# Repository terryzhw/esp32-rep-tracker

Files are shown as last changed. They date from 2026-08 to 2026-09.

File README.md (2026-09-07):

# Curl Tracker: Wearable Bicep Curl Coach (Work In Progress)

## What is Curl Tracker?

Curl Tracker is a wearable bicep curl tracker that uses an ESP32-C3 Super Mini alongside a MPU-6500 IMU to count reps, measure curl speed, and evaluate form in real-time. It uses a on-device classifier to distinguish good reps from common curl form faults. Curl Tracker displays live rep metrics to a SSD1306 OLED and streams data over MQTT to be plotted on a Python/matplotlib client. It also provides haptic feedback and monitoring of device state.

## Bicep-Curl Classifier
### Training:



### Collecting:


### Working Video:

## Breadboard Prototype

### Design Choices:

- Power: 3.7V LiPo (range: 3.0V - 4.2V) with a TP4056 module for charging managment. MT3608 module converts the varying 3.7V Lipo to a stable 5V source. A mechanical switch is used as a on/off switch. 

- MCU & Peripherals: ESP32-C3 Super Mini is the MCU that serves as the brain for the project. MPU-6500 IMU and SSD1306 share a I2C bus which the ESP32 uses to communicate. A push button is used to provide data collection input to label reps while gathering training data for the classifier.

- Feedback: A status LED exists which turns on if any of the electronic malfunction. The OLED displays rep count, sets, and status of MQTT. The vibration motor, paired with a flyback diode circuit for back-EMF protection, is used for haptic feedback.
  
Curl Tracker breadboard prototype

## KiCad Schematic & PCB layout 

### Design Choices: 

- ESP32-C3-MINI-1 module: Using a pre-certified module means the RF design is already done and the FCC/CE certification carries over, so I avoid the antenna layout, matching network, and re-testing that a bare C3 would require.
  
- MPU6500 → BMI270: The MPU6500 is end-of-life and no longer recommended for new designs. The BMI270 is Bosch's current-generation IMU with active vendor support and drivers in most major frameworks.
  
- TP4056 → MCP73831: Swapped the TP4056 for Microchip's MCP73831. Better documented, properly sourced through mainstream distributors, and easier to justify in a design review.
  
- MT3608 → TPS63001: A LiPo swings from 4.2 V down to 3.0 V, which straddles the 3.3 V rail from both directions. A boost-only converter or an LDO can't hold regulation across that whole range, so the TPS63001 buck-boost keeps 3.3 V stable through the full discharge curve, including the current spikes when the ESP32's radio transmits.
  
- USB-C: The current connector standard: reversible, mechanically more durable than micro-B, and what any user will already have a cable for.
  
- JST-PH for battery and motor: Keyed housings so the connectors can't be seated backwards, and they're cheap, common, and rated well past the current this board draws.

schematic
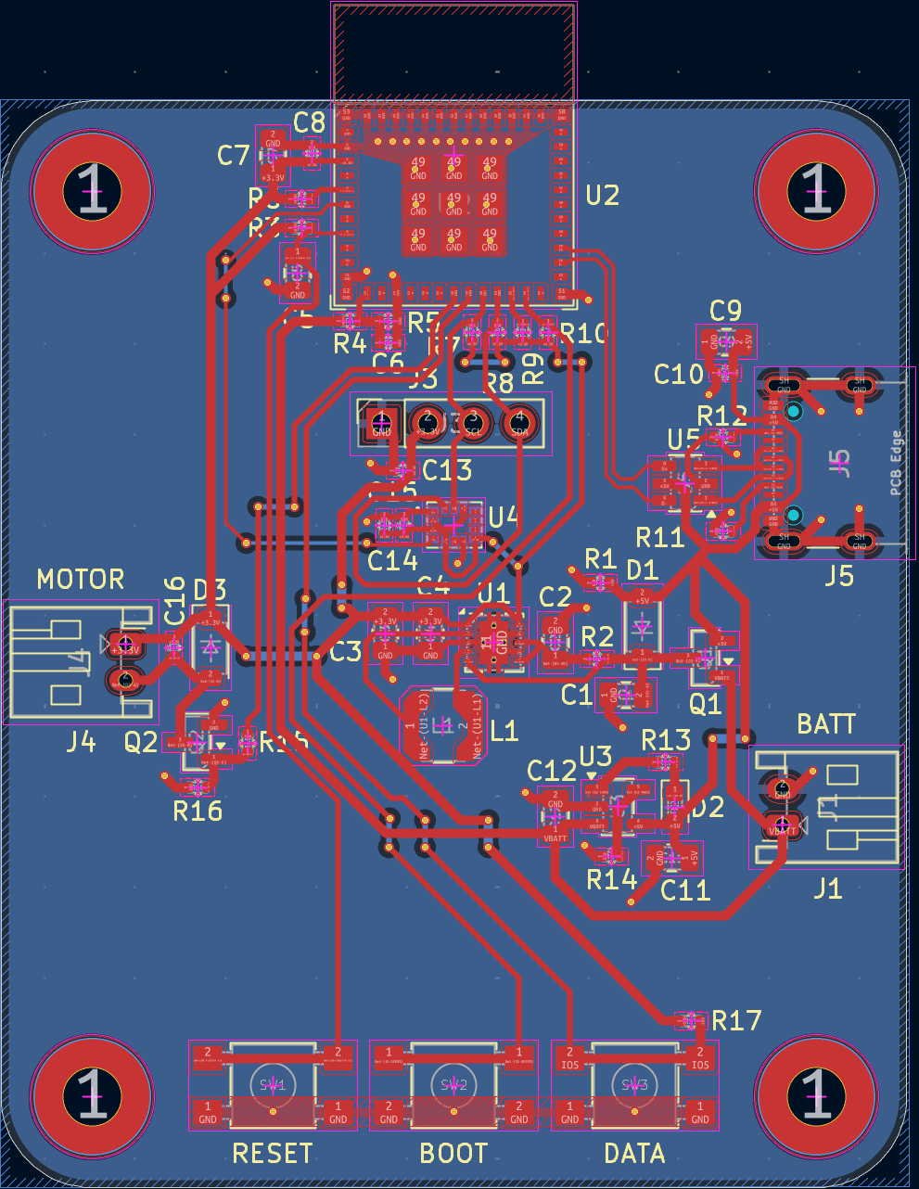
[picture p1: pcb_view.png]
pcb_view

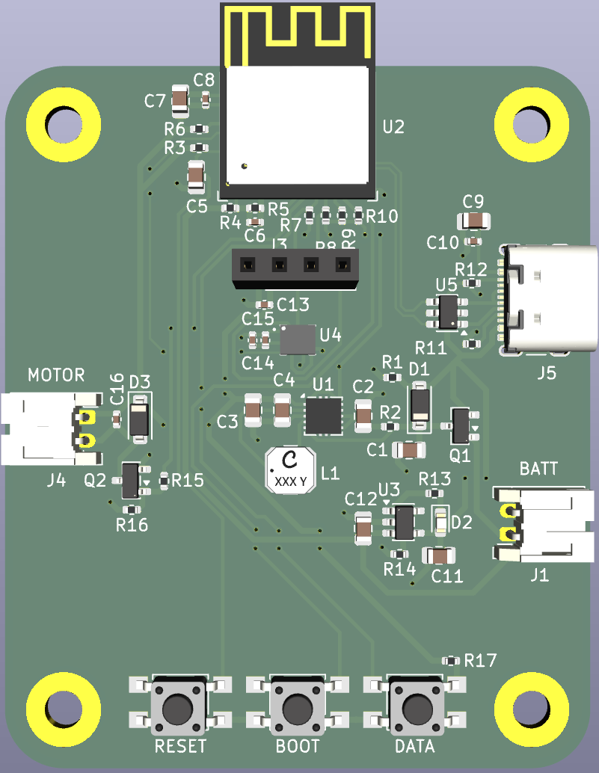
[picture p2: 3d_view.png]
3d_view

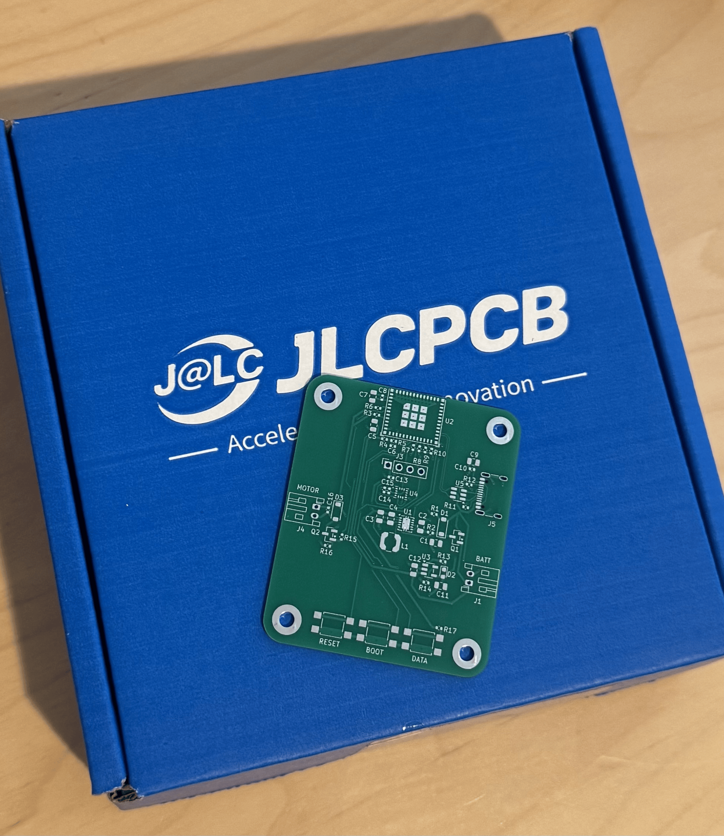
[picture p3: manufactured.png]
manufactured


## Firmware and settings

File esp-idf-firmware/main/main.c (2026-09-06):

// Bicep curl counter. IMU on the forearm -> complementary filter -> tiny NN
// that says "curling / not curling" -> count the rising edges.
//
// Split into tasks mainly because the OLED redraw is slow and blocking on it
// would wreck the 100 Hz sample timing.

#include <stdio.h>
#include <string.h>
#include <math.h>
#include <stdbool.h>

#include "freertos/FreeRTOS.h"
#include "freertos/task.h"
#include "driver/i2c.h"
#include "driver/gpio.h"
#include "driver/ledc.h"
#include "esp_timer.h"
#include "esp_log.h"

#include "hal/gpio_types.h"
#include "u8g2.h"
#include "mpu6500.h"
#include "model.h"

static const char *TAG = "curl_tracker";

#define I2C_SDA_PIN         8
#define I2C_SCL_PIN         9
#define LED_PIN             10
#define BUTTON_PIN          4
#define MOTOR_PIN           3

#define I2C_PORT            I2C_NUM_0
#define I2C_FREQ_HZ         400000

// Button pulls to ground, so pressed reads low. Naming these stops me from
// getting the polarity backwards every time I touch this code.
#define BUTTON_RELEASED     1
#define BUTTON_PRESSED      0

// Gyro is smooth but drifts, accelerometer is drift-free but jumps around
// whenever the arm accelerates. 0.9 leans on the gyro for responsiveness and
// lets gravity slowly pull the estimate back straight. Worth re-tuning if the
// angle either wanders over a long set or looks too noisy to classify.
#define ALPHA               0.90f

// Sensor runs at 1 kHz internally and divides by (1 + SRD), so this is 100 Hz.
#define SAMPLE_RATE_DIV     9
#define DT                  ((1.0f + SAMPLE_RATE_DIV) / 1000.0f)

#define RAD_TO_DEG          (180.0f / (float)M_PI)

#define IMU_PERIOD_MS       10
#define DISPLAY_PERIOD_MS   50   // shares the bus with the IMU, so don't push it
#define BUTTON_PERIOD_MS    20
#define SERIAL_PERIOD_MS    50
#define INFERENCE_PERIOD_MS 10

#define MOTOR_BUZZ_MS       200  // short enough not to overlap the next rep

#define NUM_FEATURES        2
#define INPUT_SIZE          (MODEL_WINDOW_SIZE * NUM_FEATURES)
#define HIDDEN0_SIZE        16
#define HIDDEN1_SIZE        8

#define CURL_THRESHOLD      0.5f
#define INFERENCE_STRIDE    5

static mpu6500_t imu;
static u8g2_t u8g2;

// Shared between tasks. Everything here is word sized, so a torn read isn't
// possible and I skipped the mutex.
static float roll_deg  = 0.0f;
static float pitch_deg = 0.0f;
static volatile bool filter_ready = false;
static volatile bool collecting = false;
static volatile int button_level = BUTTON_RELEASED;
static volatile int rep_count = 0;
static volatile int set_count = 0;

static TaskHandle_t motor_task_handle = NULL;

static uint32_t millis(void)
{
    return (uint32_t)(esp_timer_get_time() / 1000ULL);
}

// u8g2 is platform agnostic, so it calls back into these two for delays and
// for anything that touches the bus.
static uint8_t u8x8_gpio_and_delay_esp32(u8x8_t *u8x8, uint8_t msg,
                                         uint8_t arg_int, void *arg_ptr)
{
    switch (msg) {
        case U8X8_MSG_DELAY_MILLI:
            vTaskDelay(pdMS_TO_TICKS(arg_int));
            break;
        case U8X8_MSG_GPIO_AND_DELAY_INIT:
            break;
        default:
            break;
    }
    return 1;
}

// Collect the whole frame first and send it as one transaction. A separate
// I2C transfer per byte would spend most of the time on start/stop overhead.
static uint8_t u8x8_byte_esp32_i2c(u8x8_t *u8x8, uint8_t msg,
                                   uint8_t arg_int, void *arg_ptr)
{
    static uint8_t buf[128];
    static size_t buf_idx;
    uint8_t *data;

    switch (msg) {
        case U8X8_MSG_BYTE_START_TRANSFER:
            buf_idx = 0;
            break;

        case U8X8_MSG_BYTE_SEND:
            data = (uint8_t *)arg_ptr;
            while (arg_int > 0) {
                buf[buf_idx++] = *data++;
                arg_int--;
            }
            break;

        case U8X8_MSG_BYTE_END_TRANSFER: {
            // u8g2 keeps the address pre-shifted, ESP-IDF wants the raw 7 bits
            uint8_t addr = u8x8_GetI2CAddress(u8x8) >> 1;
            i2c_master_write_to_device(I2C_PORT, addr, buf, buf_idx,
                                       pdMS_TO_TICKS(100));
            break;
        }

        case U8X8_MSG_BYTE_INIT:
        case U8X8_MSG_BYTE_SET_DC:
            // bus is already up, and I2C has no DC line
            break;
    }
    return 1;
}

static void i2c_bus_init(void)
{
    i2c_config_t conf = {
        .mode = I2C_MODE_MASTER,
        .sda_io_num = I2C_SDA_PIN,
        .scl_io_num = I2C_SCL_PIN,
        .sda_pullup_en = GPIO_PULLUP_ENABLE,
        .scl_pullup_en = GPIO_PULLUP_ENABLE,
        .master.clk_speed = I2C_FREQ_HZ,
    };
    i2c_param_config(I2C_PORT, &conf);
    i2c_driver_install(I2C_PORT, I2C_MODE_MASTER, 0, 0, 0);
}

static bool imu_init(void)
{
    if (!mpu6500_init(&imu, I2C_PORT)) {
        return false;
    }

    // 4 g leaves headroom over the 1 g resting reading for the fast part of
    // the curl. A curl is around 1 Hz, so the 20 Hz low pass drops tremor and
    // strap slap without touching the motion I care about.
    mpu6500_set_accel_range(&imu, MPU6500_ACCEL_RANGE_4G);
    mpu6500_set_gyro_range(&imu, MPU6500_GYRO_RANGE_500DPS);
    mpu6500_set_dlpf(&imu, MPU6500_DLPF_20HZ);
    mpu6500_set_srd(&imu, SAMPLE_RATE_DIV);
    return true;
}

static void task_sample_imu(void *pv)
{
    ESP_LOGI(TAG, "IMU task started");

    if (!imu_init()) {
        ESP_LOGE(TAG, "Error starting IMU");
        vTaskDelete(NULL);
        return;
    }
    ESP_LOGI(TAG, "IMU initialized OK");

    // Header for the logging mode below, so the capture can be piped straight
    // into a csv and loaded by the training script.
    printf("timestamp_ms,roll,pitch,label\n");

    for (;;) {
        if (mpu6500_read(&imu)) {
            float ax = imu.accel[0];
            float ay = imu.accel[1];
            float az = imu.accel[2];
            float gx = imu.gyro[0];
            float gy = imu.gyro[1];

            // Gravity is the only absolute reference we have for tilt.
            float accel_roll  = atan2f(ay, -az) * RAD_TO_DEG;
            float accel_pitch = atan2f(-ax, sqrtf(ay * ay + az * az)) * RAD_TO_DEG;

            if (!filter_ready) {
                // Start from the accelerometer, otherwise the first couple of
                // seconds are spent crawling up from zero and the model sees
                // garbage.
                roll_deg  = accel_roll;
                pitch_deg = accel_pitch;
                filter_ready = true;
            } else {
                roll_deg  = ALPHA * (roll_deg  + gx * RAD_TO_DEG * DT)
                          + (1.0f - ALPHA) * accel_roll;
                pitch_deg = ALPHA * (pitch_deg + gy * RAD_TO_DEG * DT)
                          + (1.0f - ALPHA) * accel_pitch;
            }

            if (collecting) {
                // Holding the button is how I label a rep while recording.
                int label = (button_level == BUTTON_PRESSED) ? 1 : 0;
                printf("%lu,%.2f,%.2f,%d\n",
                       (unsigned long)millis(), roll_deg, pitch_deg, label);
            }
        }

        vTaskDelay(pdMS_TO_TICKS(IMU_PERIOD_MS));
    }
}

static void task_display_oled(void *pv)
{
    u8g2_Setup_ssd1306_i2c_128x64_noname_f(&u8g2, U8G2_R0,
                                           u8x8_byte_esp32_i2c,
                                           u8x8_gpio_and_delay_esp32);
    u8g2_InitDisplay(&u8g2);
    u8g2_SetPowerSave(&u8g2, 0);
    u8g2_SetFont(&u8g2, u8g2_font_helvR08_tr);

    for (;;) {
        u8g2_ClearBuffer(&u8g2);

        // Filled box then color 0 text is how you get inverted video here,
        // there's no invert flag in u8g2.
        u8g2_SetDrawColor(&u8g2, 1);
        u8g2_DrawBox(&u8g2, 0, 0, 128, 12);
        u8g2_SetDrawColor(&u8g2, 0);
        u8g2_DrawStr(&u8g2, 20, 10, "CURL TRACKER");
        u8g2_SetDrawColor(&u8g2, 1);

        char line[32];
        snprintf(line, sizeof(line), "REPS: %d", rep_count);
        u8g2_DrawStr(&u8g2, 0, 28, line);

        snprintf(line, sizeof(line), "SETS: %d", set_count);
        u8g2_DrawStr(&u8g2, 0, 42, line);

        u8g2_DrawStr(&u8g2, 0, 56, "MQTT:OK");

        u8g2_SendBuffer(&u8g2);

        vTaskDelay(pdMS_TO_TICKS(DISPLAY_PERIOD_MS));
    }
}

static void task_sample_button(void *pv)
{
    gpio_config_t io_conf = {
        .pin_bit_mask = (1ULL << BUTTON_PIN) | (1ULL << LED_PIN),
        .mode = GPIO_MODE_INPUT,
        .pull_up_en = GPIO_PULLUP_ENABLE,
    };
    gpio_config(&io_conf);

    // Both pins went through gpio_config as inputs, so put the LED back.
    gpio_set_direction(LED_PIN, GPIO_MODE_OUTPUT);

    for (;;) {
        button_level = gpio_get_level(BUTTON_PIN);

        // LED is just so I can see the label state while recording data.
        gpio_set_level(LED_PIN, button_level == BUTTON_PRESSED ? 1 : 0);

        vTaskDelay(pdMS_TO_TICKS(BUTTON_PERIOD_MS));
    }
}

static void task_vibrate_motor(void *pv)
{
    gpio_config_t motor_conf = {
        .pin_bit_mask = (1ULL << MOTOR_PIN),
        .mode = GPIO_MODE_OUTPUT,
        .pull_up_en = GPIO_PULLUP_DISABLE,
        .pull_down_en = GPIO_PULLDOWN_DISABLE,
        .intr_type = GPIO_INTR_DISABLE,
    };
    gpio_config(&motor_conf);

    for (;;) {
        // The buzz lives in its own task so the 200 ms delay doesn't stall
        // inference. Notifications are cheaper than a queue and there's
        // nothing to pass along anyway.
        ulTaskNotifyTake(pdTRUE, portMAX_DELAY);

        gpio_set_level(MOTOR_PIN, 1);
        vTaskDelay(pdMS_TO_TICKS(MOTOR_BUZZ_MS));
        gpio_set_level(MOTOR_PIN, 0);
    }
}

// Circular buffer of the last MODEL_WINDOW_SIZE angle pairs.
static float window_roll[MODEL_WINDOW_SIZE];
static float window_pitch[MODEL_WINDOW_SIZE];
static int window_idx = 0;
static bool window_full = false;

static inline float relu(float x)
{
    return x > 0.0f ? x : 0.0f;
}

static inline float sigmoid(float x)
{
    return 1.0f / (1.0f + expf(-x));
}

// Weights are exported row major from the training script, so the index math
// below has to match that layout exactly.
static float run_model(const float *input)
{
    float hidden0[HIDDEN0_SIZE];
    for (int j = 0; j < HIDDEN0_SIZE; j++) {
        float sum = BIAS0[j];
        for (int i = 0; i < INPUT_SIZE; i++) {
            sum += input[i] * WEIGHT0[i * HIDDEN0_SIZE + j];
        }
        hidden0[j] = relu(sum);
    }

    float hidden1[HIDDEN1_SIZE];
    for (int j = 0; j < HIDDEN1_SIZE; j++) {
        float sum = BIAS1[j];
        for (int i = 0; i < HIDDEN0_SIZE; i++) {
            sum += hidden0[i] * WEIGHT1[i * HIDDEN1_SIZE + j];
        }
        hidden1[j] = relu(sum);
    }

    float sum = BIAS2[0];
    for (int i = 0; i < HIDDEN1_SIZE; i++) {
        sum += hidden1[i] * WEIGHT2[i];
    }
    return sigmoid(sum);
}

// Unwrap the circular buffer oldest first and apply the same min/max scaling
// the model was trained with. Feeding it raw degrees gives nonsense output.
static void build_model_input(float *input)
{
    for (int i = 0; i < MODEL_WINDOW_SIZE; i++) {
        int ri = (window_idx + i) % MODEL_WINDOW_SIZE;
        input[i * NUM_FEATURES + 0] =
            (window_roll[ri]  - NORM_MIN[0]) / (NORM_MAX[0] - NORM_MIN[0] + 1e-7f);
        input[i * NUM_FEATURES + 1] =
            (window_pitch[ri] - NORM_MIN[1]) / (NORM_MAX[1] - NORM_MIN[1] + 1e-7f);
    }
}

static void task_inference(void *pv)
{
    bool was_curling = false;
    int samples_since_inference = 0;

    // No point buffering the startup transient.
    while (!filter_ready) {
        vTaskDelay(pdMS_TO_TICKS(100));
    }

    for (;;) {
        window_roll[window_idx]  = roll_deg;
        window_pitch[window_idx] = pitch_deg;
        window_idx++;
        if (window_idx >= MODEL_WINDOW_SIZE) {
            window_full = true;
            window_idx = 0;
        }

        samples_since_inference++;

        // Back to back windows share 49 of 50 samples, so running the model
        // every time would be almost pure wasted math.
        if (window_full && samples_since_inference >= INFERENCE_STRIDE) {
            samples_since_inference = 0;

            float input[INPUT_SIZE];
            build_model_input(input);

            bool is_curling = run_model(input) > CURL_THRESHOLD;

            // Rising edge only. The classifier stays high for the whole curl,
            // so counting on the level would add a rep every inference.
            if (is_curling && !was_curling) {
                rep_count++;
                xTaskNotifyGive(motor_task_handle);
            }
            was_curling = is_curling;
        }

        vTaskDelay(pdMS_TO_TICKS(INFERENCE_PERIOD_MS));
    }
}

// 's' over the serial monitor toggles data capture for training.
static void task_serial_control(void *pv)
{
    for (;;) {
        int c = getchar();
        if (c == 's') {
            collecting = !collecting;
            printf(collecting ? "Collecting start\n" : "Collecting stop\n");
        }
        vTaskDelay(pdMS_TO_TICKS(SERIAL_PERIOD_MS));
    }
}

void app_main(void)
{
    i2c_bus_init();

    // Equal priority everywhere, each task blocks on its own delay, so the
    // scheduler just round-robins. Inference gets the big stack because the
    // input vector and hidden layers are all on it.
    xTaskCreate(task_sample_imu,     "sampleIMU",    4096, NULL, 1, NULL);
    xTaskCreate(task_display_oled,   "displayOLED",  4096, NULL, 1, NULL);
    xTaskCreate(task_sample_button,  "sampleButton", 2048, NULL, 1, NULL);
    xTaskCreate(task_vibrate_motor,  "vibrateMotor", 2048, NULL, 1, &motor_task_handle);
    xTaskCreate(task_serial_control, "serialCtrl",   2048, NULL, 1, NULL);
    xTaskCreate(task_inference,      "inference",    8192, NULL, 1, NULL);
}

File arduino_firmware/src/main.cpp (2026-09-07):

#include <Arduino.h>
#include <Wire.h>
#include <math.h>

#include "mpu6500.h"
#include <U8x8lib.h>

#include "model.h"

#define I2C_SDA 8
#define I2C_SCL 9

#define ledPin 10

#define buttonPin 4

#define motorPin 3
#define motorChannel 0
#define motorFrequency 1000
#define motorResolution 8

// Complementary filter coefficient (0-1), higher = trust gyro more (smooth, less accel noise), lower = trust accel more (less drift)

static constexpr float ALPHA = 0.90f;

// IMU samples at 100 times per second which is more than enough for bicep curl (Original 1000Hz overkill)
static constexpr uint8_t SAMPLE_RATE_DIV = 9;
static constexpr float DT = (1.0f + SAMPLE_RATE_DIV) / 1000.0f;  

bfs::Mpu6500 mpu6500(&Wire, bfs::Mpu6500::I2C_ADDR_PRIM);
U8X8_SSD1306_128X64_NONAME_HW_I2C oled(U8X8_PIN_NONE);

float roll = 0.0f;
float pitch = 0.0f;

bool filterInitialized = false;
bool collecting = false;

int reps = 0;
int sets = 0;

int isPressed = 1;



void taskSampleIMU(void *pvParameters) {
  Serial.println("IMU task started, calling Begin()...");
  if (!mpu6500.Begin()) {
    Serial.println("Error starting IMU");
    vTaskDelete(NULL);
    return;
  }
  Serial.println("IMU initialized OK");

  mpu6500.ConfigAccelRange(bfs::Mpu6500::ACCEL_RANGE_4G);
  mpu6500.ConfigGyroRange(bfs::Mpu6500::GYRO_RANGE_500DPS);
  mpu6500.ConfigDlpfBandwidth(bfs::Mpu6500::DLPF_BANDWIDTH_20HZ);
  mpu6500.ConfigSrd(SAMPLE_RATE_DIV);

  Serial.println("timestamp_ms,roll,label");

  for (;;) {
    if (mpu6500.Read()) {
      float ax = mpu6500.accel_x_mps2();
      float ay = mpu6500.accel_y_mps2();
      float az = mpu6500.accel_z_mps2();

      float gx = mpu6500.gyro_x_radps();
      float gy = mpu6500.gyro_y_radps();
      float gz = mpu6500.gyro_z_radps();

      // Complementary filter; no yaw since not needed for bicep curls and no magnetometer to prevent drift

      float accelRoll = atan2f(ay, -az) * (180.0f / M_PI);
      float accelPitch = atan2f(-ax, sqrtf(sq(ay) + sq(az))) * (180.0f / M_PI);

      if (!filterInitialized) {
        roll = accelRoll;
        pitch = accelPitch;
        filterInitialized = true;
      } else {
        roll = ALPHA * (roll + gx * (180.0f / M_PI) * DT)
             + (1.0f - ALPHA) * accelRoll;
        pitch = ALPHA * (pitch + gy * (180.0f / M_PI) * DT)
              + (1.0f - ALPHA) * accelPitch;
      }

      // collect.py reads this to write to data.csv
      if (collecting) {
        int label = (isPressed == LOW) ? 1 : 0;
        Serial.print(millis());
        Serial.print(",");
        Serial.print(roll, 2);
        Serial.print(",");
        Serial.print(pitch, 2);
        Serial.print(",");
        Serial.println(label);
      }
    }

    vTaskDelay(pdMS_TO_TICKS(10));
  }
}

void taskDisplayOLED(void *pvParameters) {

  oled.begin();
  oled.setFlipMode(0);

  oled.setFont(u8x8_font_chroma48medium8_r);

  oled.inverse();
  oled.setCursor(2,0);
  oled.print("CURL TRACKER");
  oled.noInverse();

  for(;;) {
    oled.setCursor(0,2);
    oled.print("REPS:");
    oled.setCursor(5,2);
    oled.print(reps, 1);

    oled.setCursor(0,4);
    oled.print("SETS:");
    oled.setCursor(5,4);
    oled.print(sets, 1);

    oled.setCursor(0,6);
    oled.print("MQTT:OK");

    vTaskDelay(pdMS_TO_TICKS(50));
  }
}

void taskSampleButton(void *pvParameters) {

  pinMode(buttonPin, INPUT_PULLUP);
  pinMode(ledPin, OUTPUT);

  for (;;) {
    isPressed = digitalRead(buttonPin);


    if (isPressed == HIGH) {
      digitalWrite(ledPin, LOW);
    } else {
      digitalWrite(ledPin, HIGH);
    }

    vTaskDelay(pdMS_TO_TICKS(20));
  }
}

// Haptic feedback for curls
void taskVibrateMotor(void *pvParamters) {

  ledcSetup(motorChannel, motorFrequency, motorResolution);
  ledcAttachPin(motorPin, motorChannel);
  ledcWrite(motorChannel, 0);

  for(;;) {
    if (isPressed == LOW) {
      ledcWrite(motorChannel, 220);
      vTaskDelay(pdMS_TO_TICKS(20));
      ledcWrite(motorChannel, 0);
    }
    vTaskDelay(pdMS_TO_TICKS(20));
  }
}

// Direct neural network inference for rep counting (no TFLite needed)
static float win_roll[MODEL_WINDOW_SIZE];
static float win_pitch[MODEL_WINDOW_SIZE];
static int win_idx = 0;
static bool win_full = false;

static inline float relu(float x) { return x > 0.0f ? x : 0.0f; }

static constexpr int INPUT_SIZE = MODEL_WINDOW_SIZE * 2;

static float runModel(const float *input) {
  // Layer 0: Dense(INPUT_SIZE → 16, relu)
  float h0[16];
  for (int j = 0; j < 16; j++) {
    float sum = BIAS0[j];
    for (int i = 0; i < INPUT_SIZE; i++) sum += input[i] * WEIGHT0[i * 16 + j];
    h0[j] = relu(sum);
  }
  // Layer 1: Dense(16 → 8, relu)
  float h1[8];
  for (int j = 0; j < 8; j++) {
    float sum = BIAS1[j];
    for (int i = 0; i < 16; i++) sum += h0[i] * WEIGHT1[i * 8 + j];
    h1[j] = relu(sum);
  }
  // Layer 2: Dense(8 → 1, sigmoid)
  float sum = BIAS2[0];
  for (int i = 0; i < 8; i++) sum += h1[i] * WEIGHT2[i];
  return 1.0f / (1.0f + expf(-sum));
}

void taskInference(void *pvParameters) {
  bool was_curling = false;
  int step_count = 0;

  while (!filterInitialized) vTaskDelay(pdMS_TO_TICKS(100));

  for (;;) {
    win_roll[win_idx]  = roll;
    win_pitch[win_idx] = pitch;
    win_idx++;
    if (win_idx >= MODEL_WINDOW_SIZE) {
      win_full = true;
      win_idx  = 0;
    }

    step_count++;

    if (win_full && step_count >= 5) {
      step_count = 0;

      // Normalize and flatten into (INPUT_SIZE,) input
      float input[INPUT_SIZE];
      for (int i = 0; i < MODEL_WINDOW_SIZE; i++) {
        int ri = (win_idx + i) % MODEL_WINDOW_SIZE;
        input[i * 2 + 0] = (win_roll[ri]  - NORM_MIN[0]) / (NORM_MAX[0] - NORM_MIN[0] + 1e-7f);
        input[i * 2 + 1] = (win_pitch[ri] - NORM_MIN[1]) / (NORM_MAX[1] - NORM_MIN[1] + 1e-7f);
      }

      float prob = runModel(input);
      bool is_curling = prob > 0.5f;

      if (is_curling && !was_curling) {
        reps++;
      }
      was_curling = is_curling;
    }

    vTaskDelay(pdMS_TO_TICKS(10));
  }
}

// Toggle for data collection
void taskSerialControl(void *pvParameters) {
  for (;;) {
    if (Serial.available()) {
      char c = Serial.read();
      if (c == 's') {
        collecting = !collecting;
        if (collecting) {
          Serial.println("Collecting start");
        } else {
          Serial.println("Collecting stop");
        }
      }
    }
    vTaskDelay(pdMS_TO_TICKS(50));
  }
}

void setup() {
  Serial.begin(9600);
  Wire.begin(I2C_SDA, I2C_SCL);
  Wire.setClock(400000);
  xTaskCreate(taskSampleIMU, "sampleIMU", 2048, NULL, 1, NULL);
  xTaskCreate(taskDisplayOLED, "displayOLED", 2048, NULL, 1, NULL);
  xTaskCreate(taskSampleButton, "sampleButton", 2048, NULL, 1, NULL);
  xTaskCreate(taskVibrateMotor, "vibrateMotor", 2048, NULL, 1, NULL);
  xTaskCreate(taskSerialControl, "serialCtrl", 2048, NULL, 1, NULL);
  xTaskCreate(taskInference, "inference", 8192, NULL, 1, NULL);
}

void loop() {
  vTaskDelay(pdMS_TO_TICKS(1000));
}

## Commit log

2026-08-08 begin pcb layout and trace
    [curl_tracker.kicad_pcb, curl_tracker.kicad_sch]
2026-08-16 finished pcb
    [curl_tracker.kicad_pcb, curl_tracker.kicad_sch]
2026-08-16 Add PCB and 3D view images to README
2026-08-16 Fix image link for PCB view in README
2026-08-24 first prototype of esp-idf code
2026-09-07 Update README with new images and design choices
    Added an image of the manufactured product and updated design choices for various components to reflect current recommendations.
2026-09-07 Restore images in README for schematic and PCB layout
    Re-added schematic and PCB layout images to the README.
2026-09-07 Add breadboard prototype image to README
    Added an image of the Curl Tracker breadboard prototype to the README.
2026-09-07 Add prototype image to README
    Added image of the Curl Tracker breadboard prototype to README.
2026-09-07 Update TPS63001 description in README
    Clarified explanation of TPS63001 buck-boost converter for power regulation.
